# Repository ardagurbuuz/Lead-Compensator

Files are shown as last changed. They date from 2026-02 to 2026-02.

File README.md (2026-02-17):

# Analog Lead Compensator Controller (Plant + Compensator)

This repository documents an end-to-end control + hardware workflow: **designing a lead compensator**, validating it at **model-level (MATLAB/Simulink)** and **circuit-level (SPICE tools)**, and implementing it as an **op-amp analog controller** on a **KiCad PCB**.

A benchmark plant model is used as the baseline system:

$$
G(s)=\frac{2}{s(s+1)}
$$

---

## System overview (what is being built)
The project compares two closed-loop configurations under the same input:

1. **Uncompensated loop:** plant-only closed-loop response  
2. **Compensated loop:** plant + lead compensator closed-loop response  

This block-level structure is implemented and cross-validated across tools:

<p align="center">
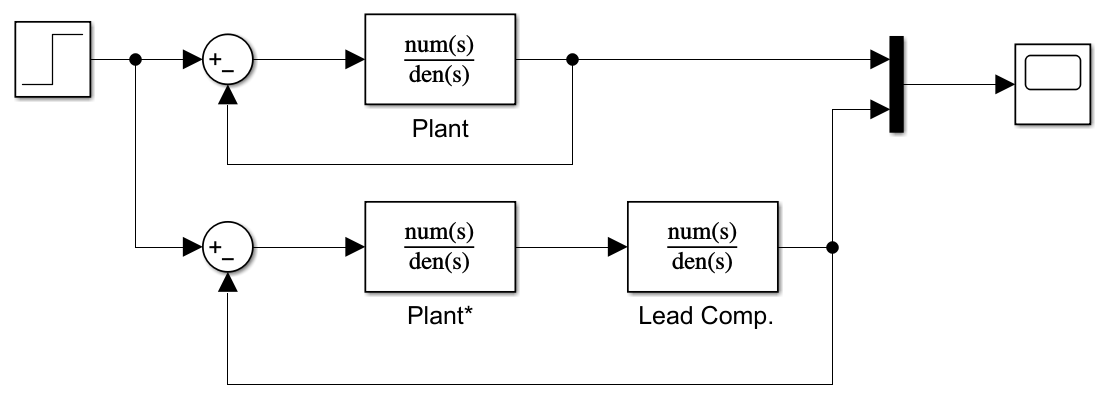
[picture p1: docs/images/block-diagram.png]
  
</p>

---

## What this project is (and why it matters)
A **lead compensator** adds **phase lead** in a chosen frequency range. Practically, it helps achieve:
- **faster transient response** (shorter settling time),
- **reduced overshoot**,
- improved stability margins when the baseline plant dynamics are “too slow” or “too oscillatory”.

### Why this plant?
The plant

`G(s) = 2 / (s(s+1))`

was chosen deliberately because it is a **clean benchmark** that exposes the core trade-offs a lead compensator is meant to address:
- The `1/s` term introduces an **integrator**, which is a common structure when the system output represents an accumulated quantity (position/angle/level).
- The `1/(s+1)` term adds a **dominant first-order lag**, a very typical dynamic limitation in real systems.
- Together, this plant is simple enough to analyze clearly, yet rich enough to show meaningful improvements in transient behavior when compensation is applied.

In short: it’s an intentional baseline that makes controller impact measurable and transferable.

---

## Design goals
The project is built around a single, clear comparison:
- **Uncompensated (plant-only)** response
vs.
- **Compensated (plant + lead compensator)** response

with the intent to improve transient performance (reduced overshoot, faster settling) while keeping the design implementable in analog hardware.

---

## Control design method (Root Locus)
The compensator was selected using **Root Locus–based design**, specifically:
- **Dominant pole targeting:** choose desired dominant closed-loop pole locations that meet transient expectations (overshoot/settling trade-off).
- **Angle condition:** determine where a compensator zero/pole should be placed so the desired pole location satisfies the Root Locus angle requirement.
- **Magnitude condition:** compute the required gain so the point lies on the locus.

This approach links performance objectives directly to pole locations and results in a compensator that is both analyzable and implementable.

---

## Verification workflow (MATLAB → Simulink → SPICE tools)
This project intentionally uses multiple tools because each one answers a different question. Using only one would leave blind spots.

### 1) MATLAB (calculation sanity-check)
MATLAB is used to verify the math: pole/zero placement logic, gain consistency, and quick numeric checks. This prevents “it looks right” errors before simulation.

### 2) Simulink (system-level behavior)
Simulink is used to observe **signals and step responses** in a clean block-diagram environment and to compare compensated vs. uncompensated outputs under the same stimulus.

<p align="center">
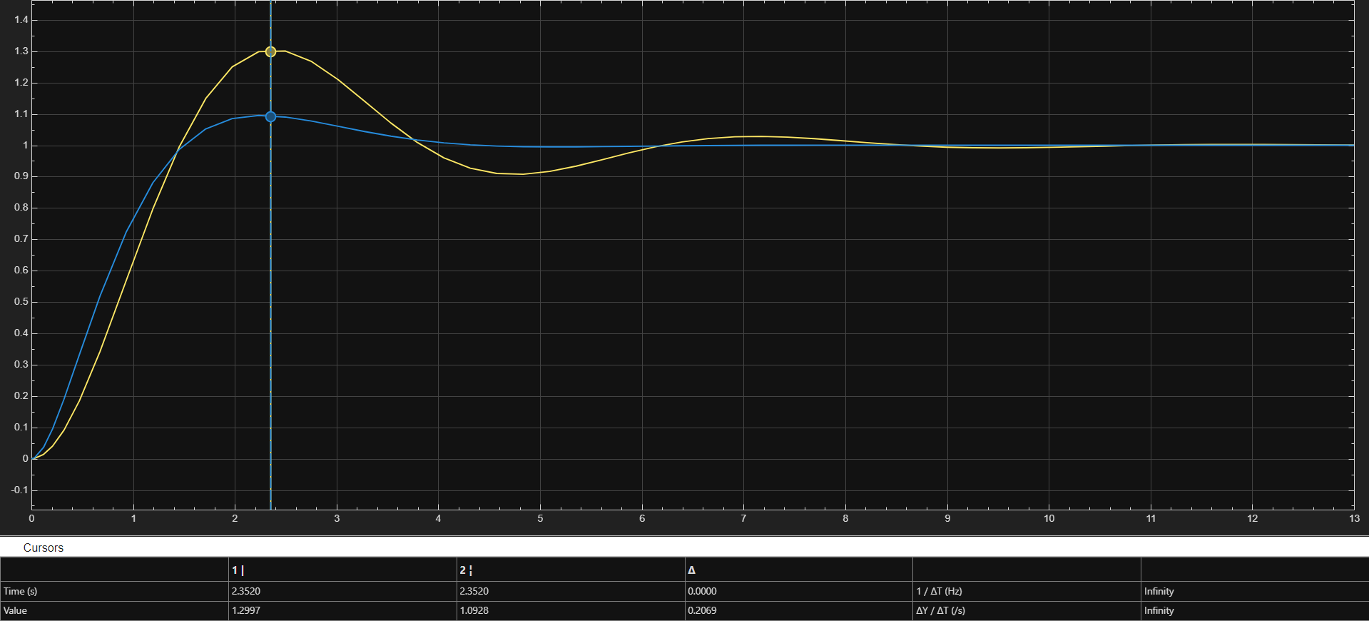
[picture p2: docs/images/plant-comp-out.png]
  
</p>

### 3) LTspice (ideal circuit-level cross-check)
LTspice is used to rebuild the control structure as **ideal analog circuits**, for two reasons:
- It verifies the design **at circuit level** (not only transfer-function level).
- It enables quick iteration and clean A/B comparison of plant-only vs. compensated behavior.

### 4) Proteus (practical pre-PCB simulation + switching)
Proteus is used as the “last realism check” before committing to PCB:
- It supports a **switch-based** workflow: using a DPDT switch model to **toggle between plant-only and compensated paths**, enabling direct comparison with the same source/instrumentation.
- It is also convenient for validating the integrated circuit behavior and wiring logic in a more “lab-like” simulation setup.

In short:
- **LTspice (SPICE tool)** = ideal, controlled circuit verification and fast iteration  
- **Proteus (SPICE tool)** = integrated validation with switching and final pre-PCB confidence

---

## Hardware implementation (Analog + PCB)
After validating behavior in simulation, the controller is implemented using **op-amp analog circuitry** and captured in KiCad as:
- schematic,
- PCB layout and routing,
- manufacturing-ready board representation.

A key constraint throughout the hardware step is **real-world component availability**:
- Some ideal resistor values from initial calculations are not standard off-the-shelf values.
- Where needed, values are realized using **series/parallel combinations** (documented/verified at simulation stage before PCB finalization).

<p align="center">
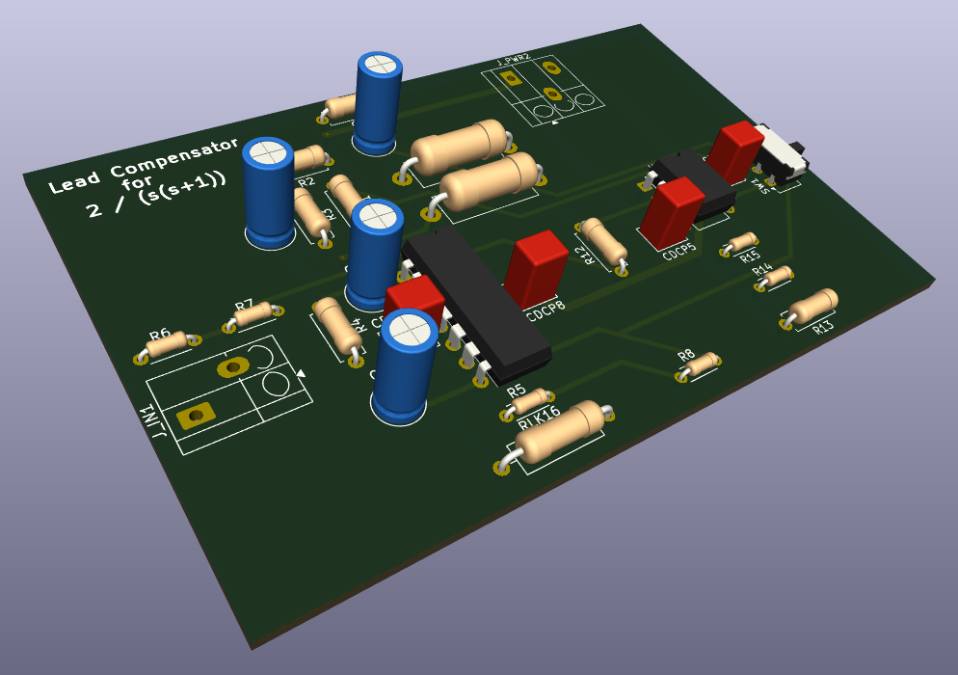
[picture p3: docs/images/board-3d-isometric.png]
  
</p>

> Fabrication note: The current PCB is a **2-layer** design. If single-sided fabrication is required, it will generally need rerouting and/or jumpers.

---

## Reproducibility (how to run / view everything)
This repo is structured so each stage can be opened independently.

### MATLAB / Simulink
Folder: `matlab-simulink/`
- `lead_compensator.m` → calculation/verification script
- `plant_comp.slx` → compensated system model
- `uncomp_step_response.slx` → baseline (plant-only) response model

Open in MATLAB/Simulink and run the script/models to reproduce the response comparison.

### LTspice
Folder: `ltspice/`
- `lead-compensator.asc` → circuit file

Open in LTspice and run the transient simulation to inspect waveforms.

### Proteus
Folder: `proteus/`
- `lead-compensator.pdsprj` → project file (includes switch-based comparison setup)

Open in Proteus, run simulation, and toggle the switch to compare modes.

### KiCad
Folder: `kicad/`
- `lead-compensator.kicad_sch` → schematic
- `lead-compensator.kicad_pcb` → PCB layout
- `lead-compensator.kicad_pro` → project settings

Open the `.kicad_pro` project file in KiCad, then inspect schematic/PCB.

---

## Repository structure
- `docs/images/` → curated images used in README
- `kicad/` → KiCad schematic + PCB
- `matlab-simulink/` → MATLAB + Simulink models
- `ltspice/` → LTspice circuit (SPICE tool)
- `proteus/` → Proteus project (SPICE tool)

---

## Tools
**MATLAB, Simulink, LTspice (SPICE tool), Proteus (SPICE tool), KiCad**

---

## Keywords (for recruiters and technical readers)
Root Locus, dominant poles, angle condition, magnitude condition, lead compensator, transient response, overshoot, settling time, circuit-level validation, op-amp analog implementation, PCB design, DRC-clean layout, end-to-end engineering workflow.

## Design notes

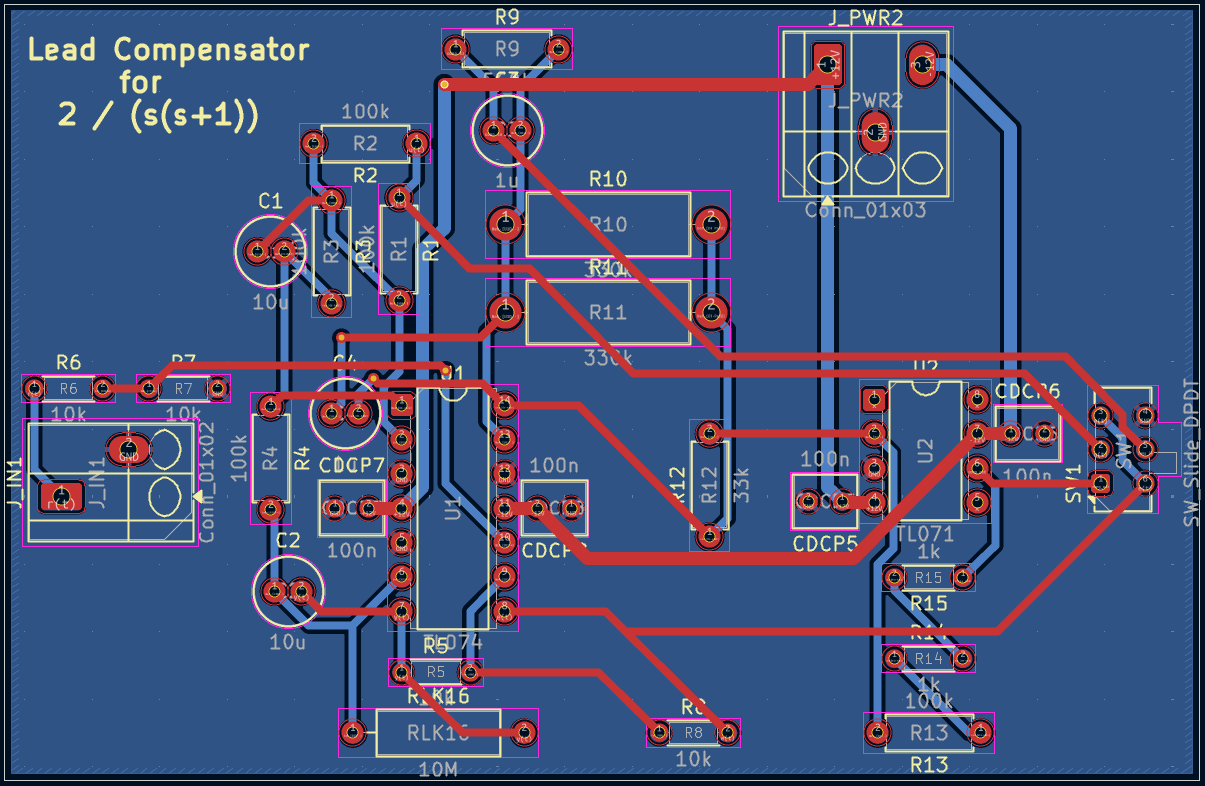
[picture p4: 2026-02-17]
docs/images/pcb-design.png

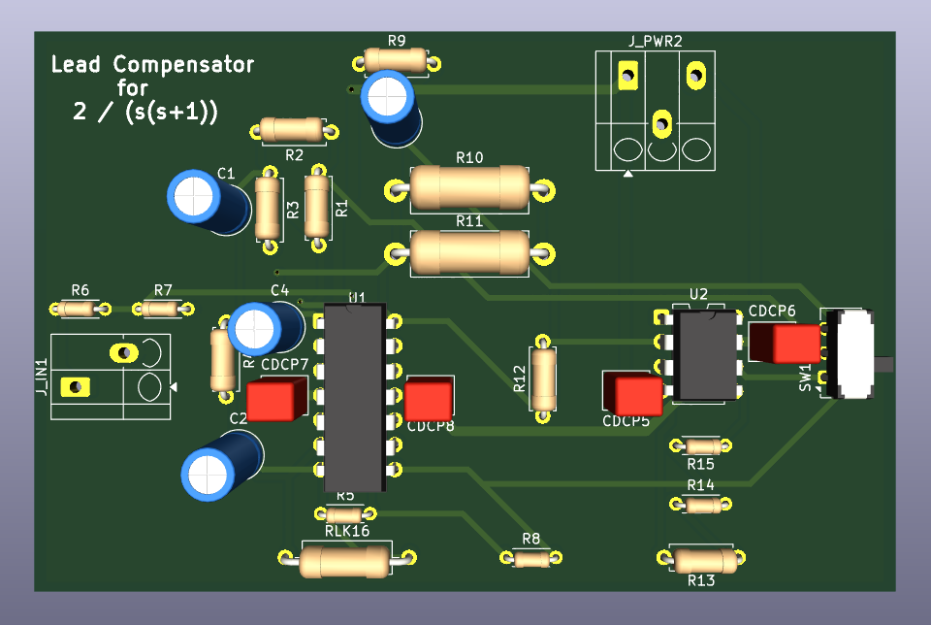
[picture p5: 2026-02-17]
docs/images/board-3d-front.png

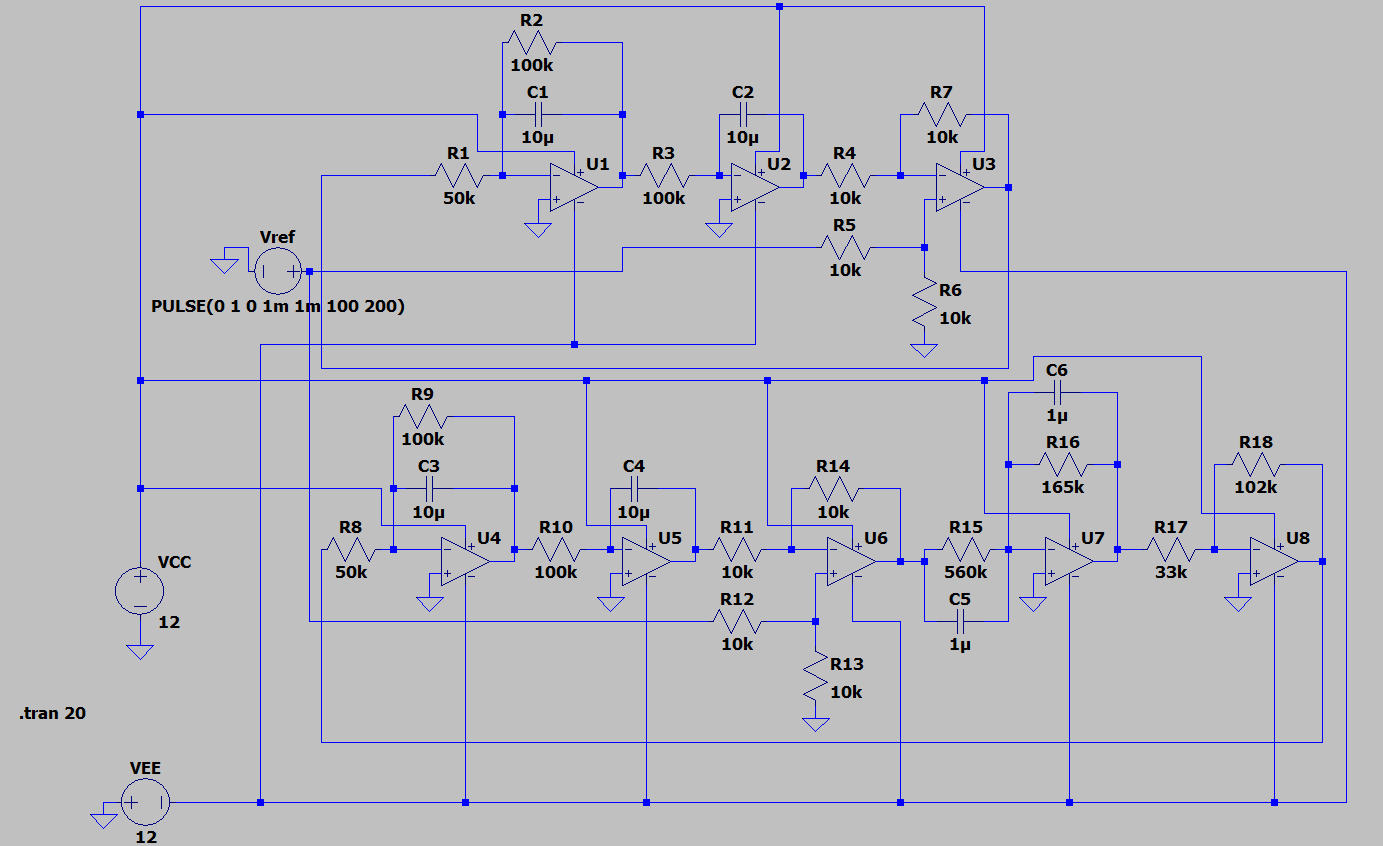
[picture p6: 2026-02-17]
docs/images/plant-comp-ideal-circuit.png

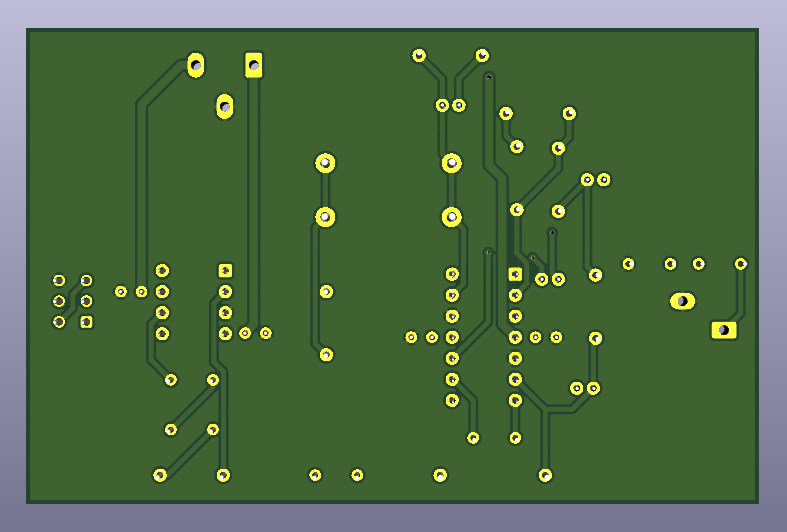
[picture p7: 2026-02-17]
docs/images/board-3d-back.png

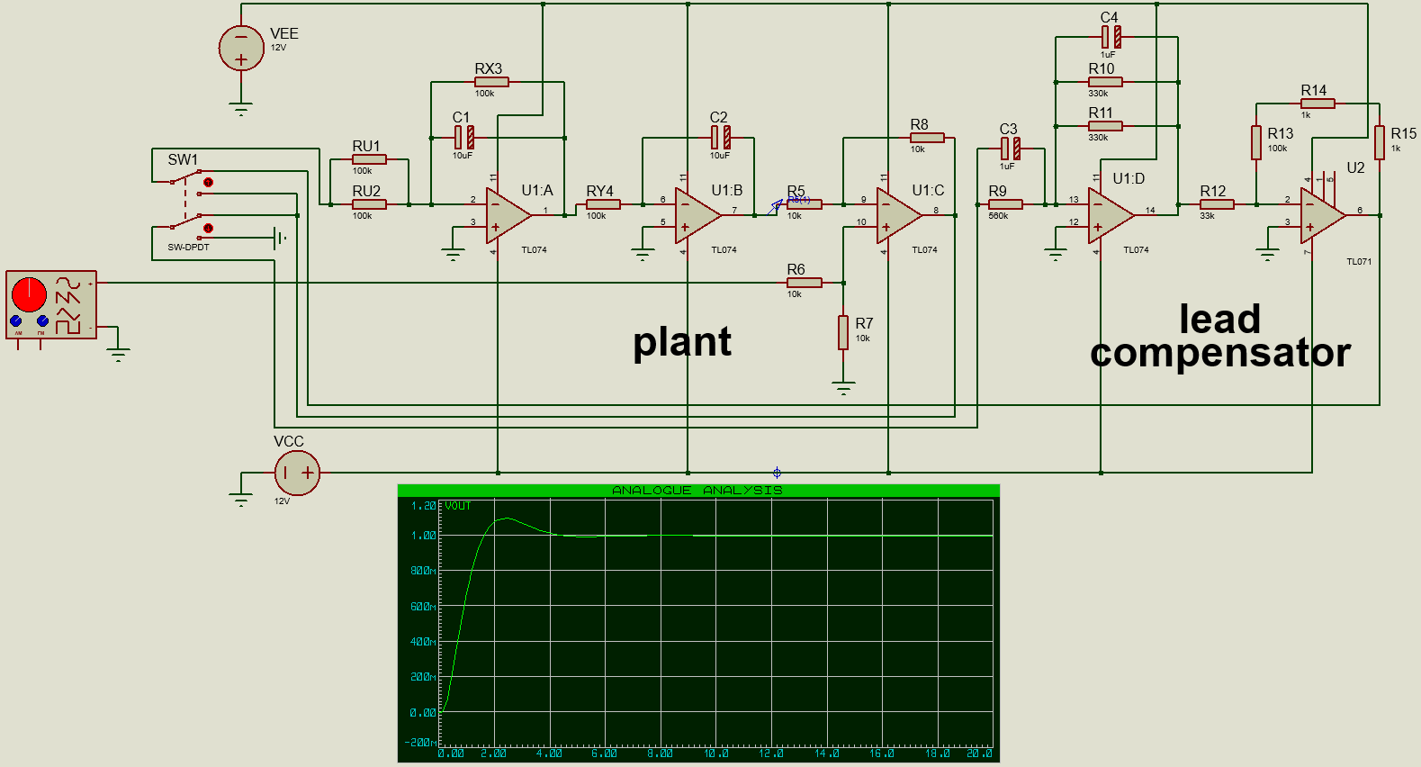
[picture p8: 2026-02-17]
docs/images/dpdt-sw-comp-circuit.png

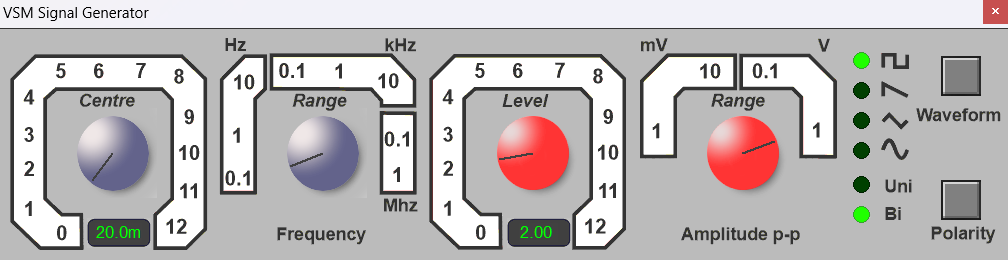
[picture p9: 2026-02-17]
docs/images/signal-gen-settings.png

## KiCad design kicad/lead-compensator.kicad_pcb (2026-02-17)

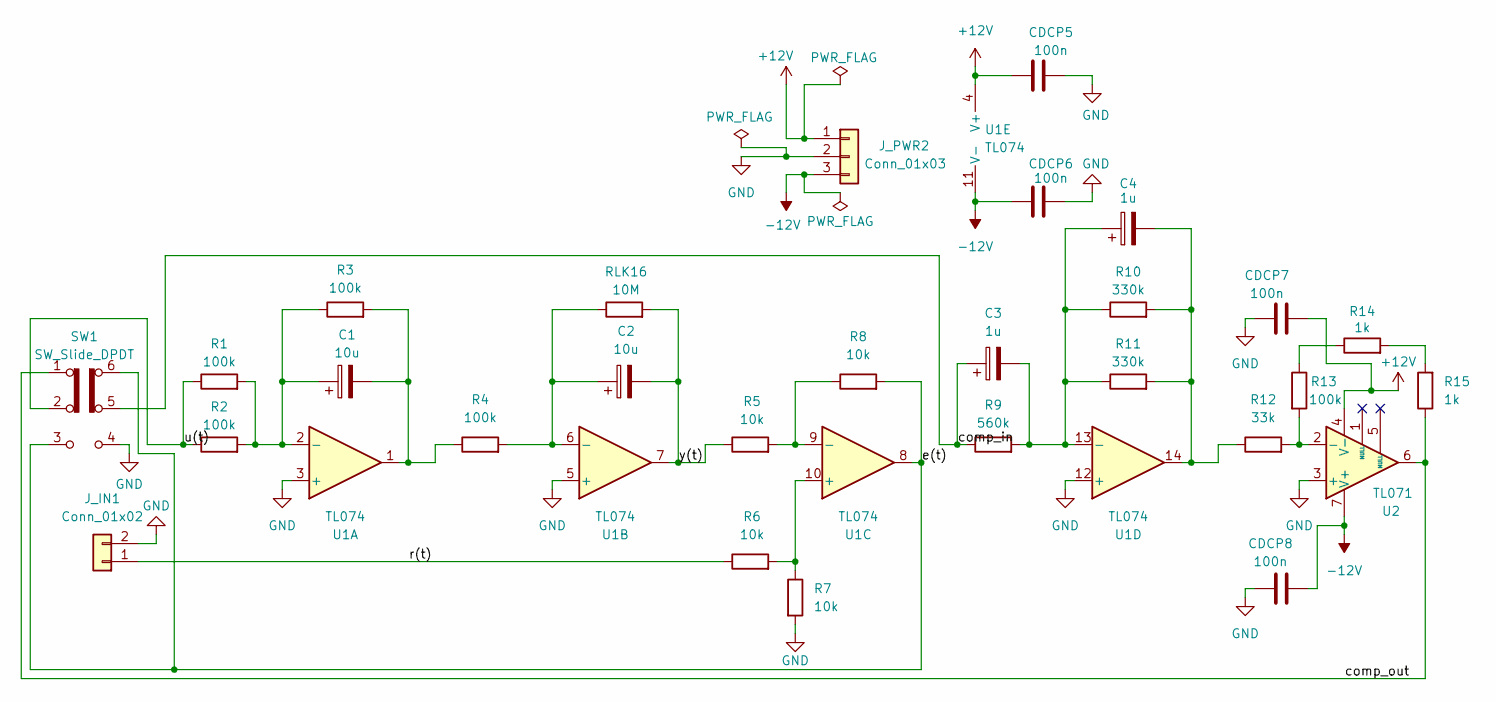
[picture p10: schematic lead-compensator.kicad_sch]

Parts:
C1, C2: 10u; C_Radial_D5.0mm_H11.0mm_P2.00mm
C3, C4: 1u; C_Radial_D5.0mm_H11.0mm_P2.00mm
CDCP5, CDCP6, CDCP7, CDCP8: 100n; C_Rect_L4.6mm_W3.8mm_P2.50mm_MKS02_FKP02
J_IN1: Conn_01x02; TerminalBlock_Degson_DG250-3.5-02P_1x02_P3.50mm_45Degree
J_PWR2: Conn_01x03; TerminalBlock_Degson_DG250-3.5-03P_1x03_P3.50mm_45Degree
R1, R2, R3, R4, R13: 100k; R_Axial_DIN0207_L6.3mm_D2.5mm_P7.62mm_Horizontal
R5, R6, R7, R8: 10k; R_Axial_DIN0204_L3.6mm_D1.6mm_P5.08mm_Horizontal
R9: 560k; R_Axial_DIN0207_L6.3mm_D2.5mm_P7.62mm_Horizontal
R10, R11: 330k; R_Axial_DIN0414_L11.9mm_D4.5mm_P15.24mm_Horizontal
R12: 33k; R_Axial_DIN0207_L6.3mm_D2.5mm_P7.62mm_Horizontal
R14, R15: 1k; R_Axial_DIN0204_L3.6mm_D1.6mm_P5.08mm_Horizontal
RLK16: 10M; R_Axial_DIN0309_L9.0mm_D3.2mm_P12.70mm_Horizontal
SW1: SW_Slide_DPDT; SW_CK_JS202011AQN_DPDT_Angled
U1: TL074; DIP-14_W7.62mm
U2: TL071; DIP-8_W7.62mm

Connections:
+12V: CDCP5.1, CDCP7.2, J_PWR2.1, U1.4 (V+), U2.4 (V-)
-12V: CDCP6.1, CDCP8.2, J_PWR2.3, U1.11 (V-), U2.7 (V+)
/comp_in: C3.1, R9.1, SW1.5 (B)
/comp_out: R15.1, SW1.1 (A), U2.6
/e(t): R8.2, SW1.3 (C), SW1.6 (C), U1.8
/r(t): J_IN1.1, R6.1
/u(t): R1.1, R2.1, SW1.2 (B)
/y(t): C2.2, R5.1, RLK16.2, U1.7
GND: CDCP5.2, CDCP6.2, CDCP7.1, CDCP8.1, J_IN1.2, J_PWR2.2, R7.2, SW1.4 (A), U1.3 (+), U1.5 (+), U1.12 (+), U2.3 (+)
unnamed: C1.2, R3.2, R4.1, U1.1
unnamed: C4.2, R10.2, R11.2, R12.1, U1.14
unnamed: R13.1, R14.1
unnamed: R14.2, R15.2
unnamed: C1.1, R1.2, R2.2, R3.1, U1.2 (-)
unnamed: C2.1, R4.2, RLK16.1, U1.6 (-)
unnamed: R6.2, R7.1, U1.10 (+)
unnamed: R5.2, R8.1, U1.9 (-)
unnamed: C3.2, C4.1, R9.2, R10.1, R11.1, U1.13 (-)
unnamed: R12.2, R13.2, U2.2 (-)

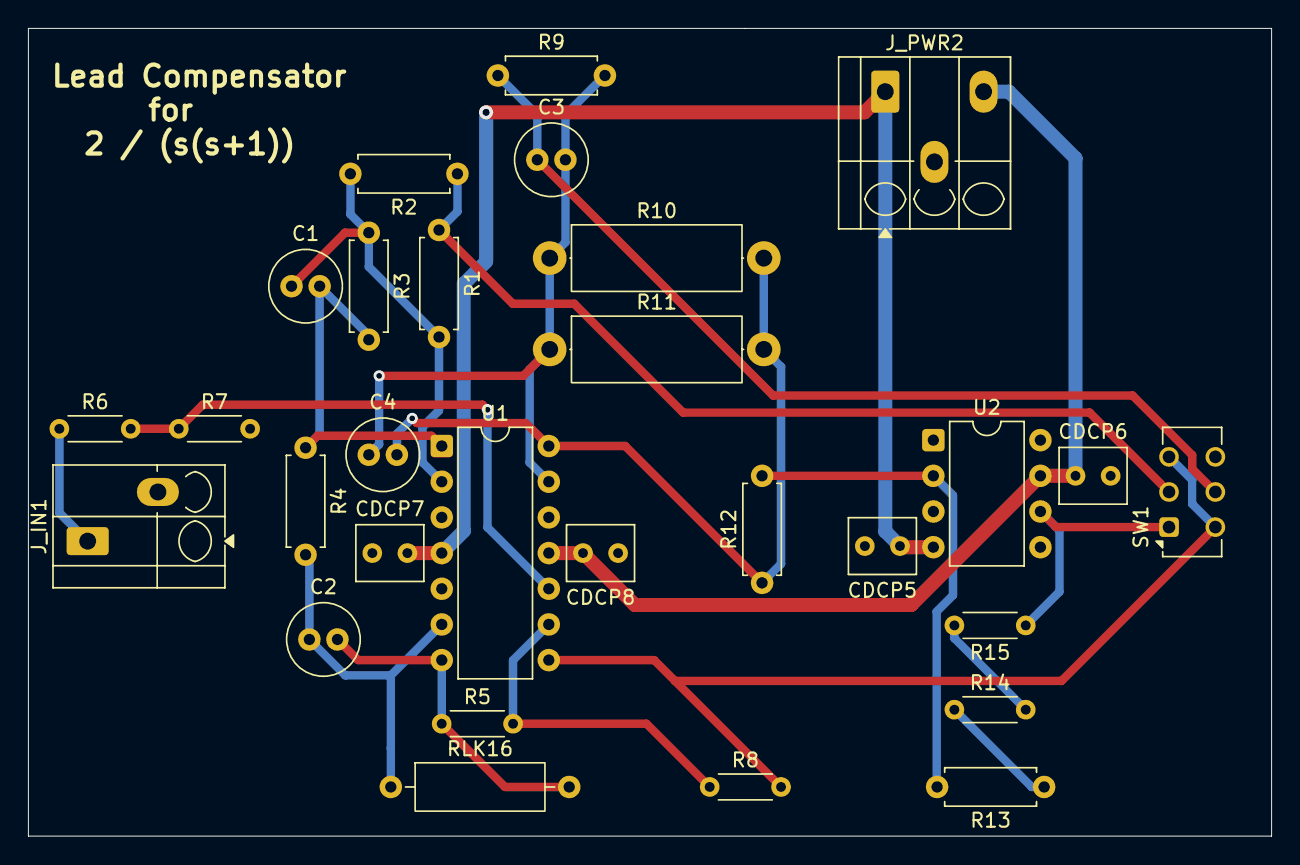
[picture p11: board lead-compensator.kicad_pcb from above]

Board: 2 copper layers, 88.5 x 57.5 mm, 29 parts (0 on the bottom side), 19 nets.
